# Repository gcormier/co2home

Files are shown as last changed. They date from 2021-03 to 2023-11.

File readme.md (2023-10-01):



# co2home
This device interfaces with an MH-Z19 and makes the data available in home assistant via esphome. It could also work with any other software you'd like on an ESP32. It is powered and programmed via a USB-C port.

Phyiscally, this should also work with the Senseair S8 as it has the same pinouts. ESPHome provides a <a href="https://esphome.io/components/sensor/senseair.html">different block</a> to work with this.

There may be other clones out there as well such as the SYP50-A-5K.

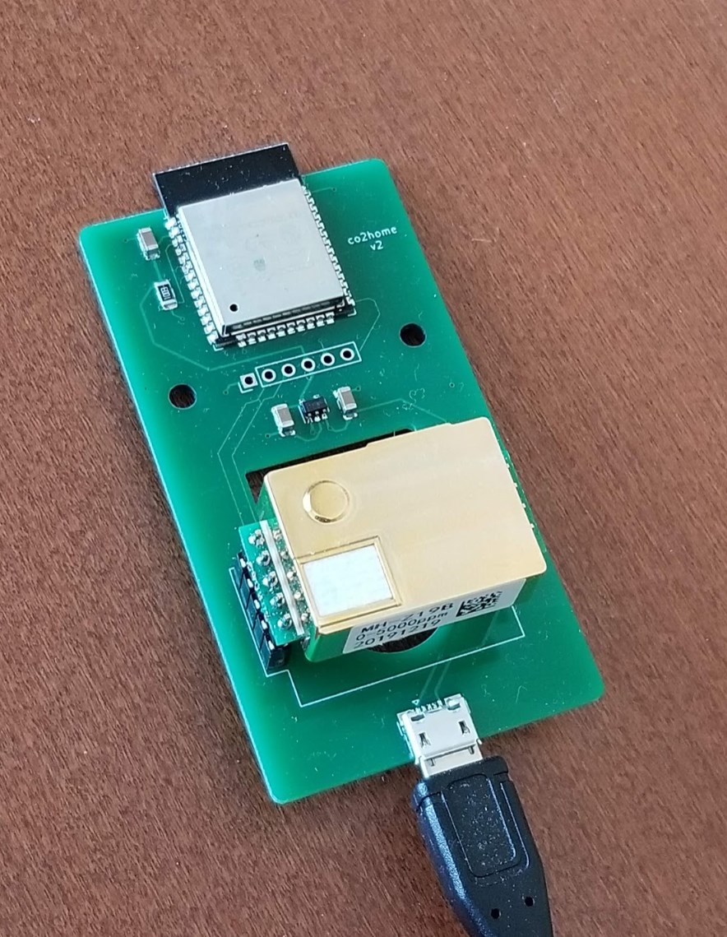
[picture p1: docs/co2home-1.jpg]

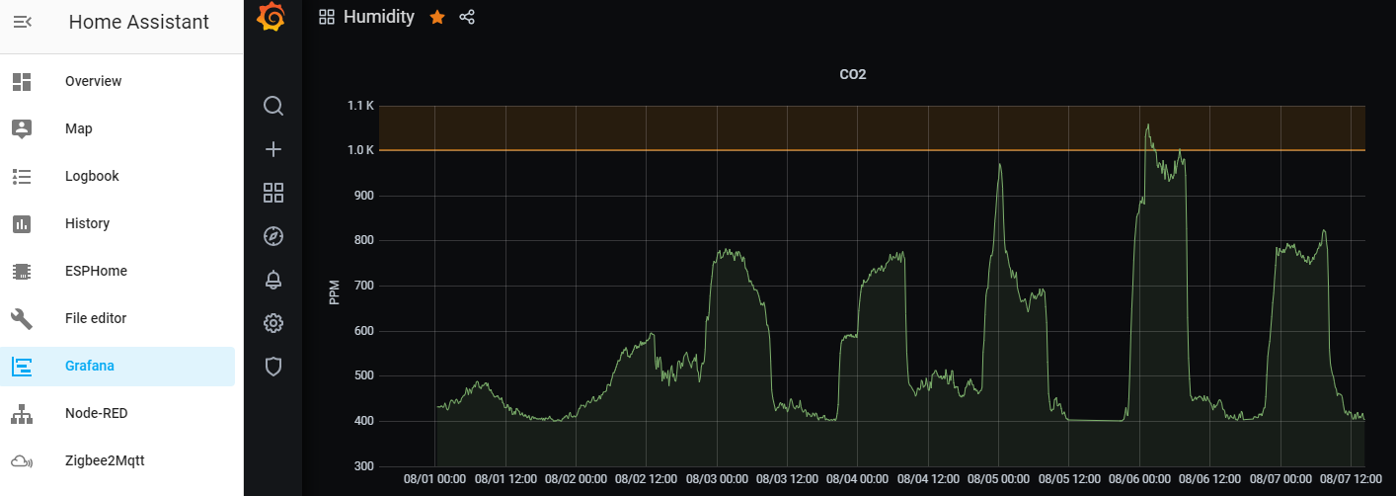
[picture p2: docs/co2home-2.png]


## Narrative
With COVID hitting and basically spending the tail end of Winter and a lot of spring indoors 24x7, I really wanted to check out the indoor air quality. My house does have an ERV, but it was basically a guessing game. No matter how efficient an ERV/HRV is, there is still a penalty to pay. I wanted a way to quantify the levels to adjust my HRV accordingly.

Now with HA and Grafana, I've dialed it in. I have the sensor in my bedroom, but I have just built another board, and I hope to put it somewhere near (or in) a duct to meter the overall CO2 levels in the house. I do want my air handler fan settings to keep the bedroom to acceptable levels at night.

I've found now that 10 minutes an hour is not quite enough ERV time with the CFM I've selected to run it at. Throughout the day, the CO2 level will slowly rise. However, at 20 minutes/hour, it is bringing in enough fresh air to keep levels from rising too much!

Overkill, sure, but hey, why not?

## Programming
The new revision uses an ESP32-C3-MINI-1 which has native USB support. This means the code can be flashed via USB. The first time this is done, you must HOLD the button while plugging in the USB-C cable to force it in programming mode. Flash using `esphome` or any other flasher. Any subsequent flashes do not need any button pushes.

As a backup, there is a programming header - the pinout matches my esp32 programmer, <a href="https://github.com/gcormier/eflashy32/">eflashy32</a> if you are in need of a programmer as well.

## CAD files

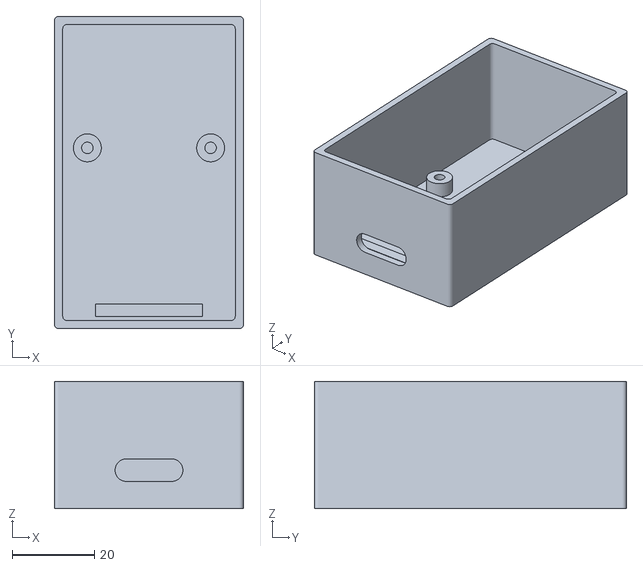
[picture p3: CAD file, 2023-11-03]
3d/co2home base.stl
46.0 x 76.0 x 31.0

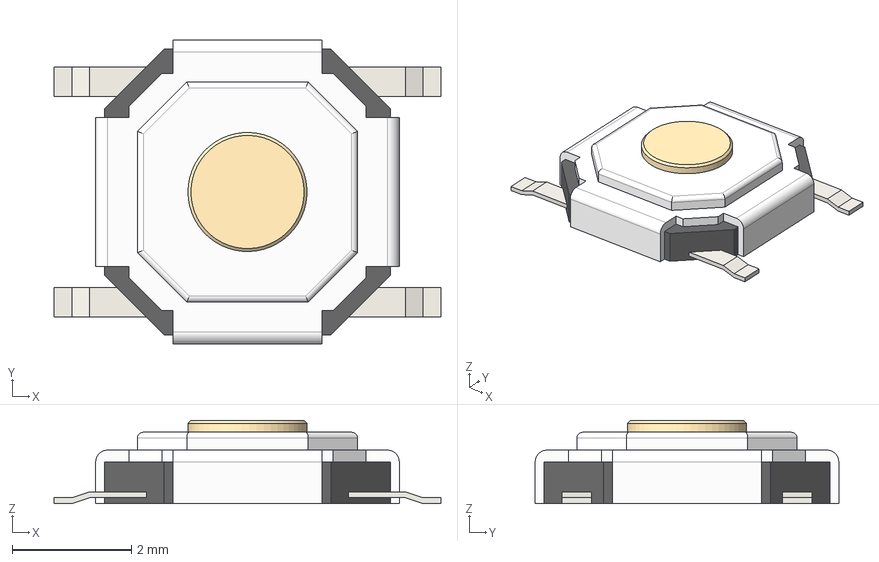
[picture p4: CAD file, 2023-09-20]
pcb/TS-1187A.step
6.50 x 5.10 x 1.40 mm

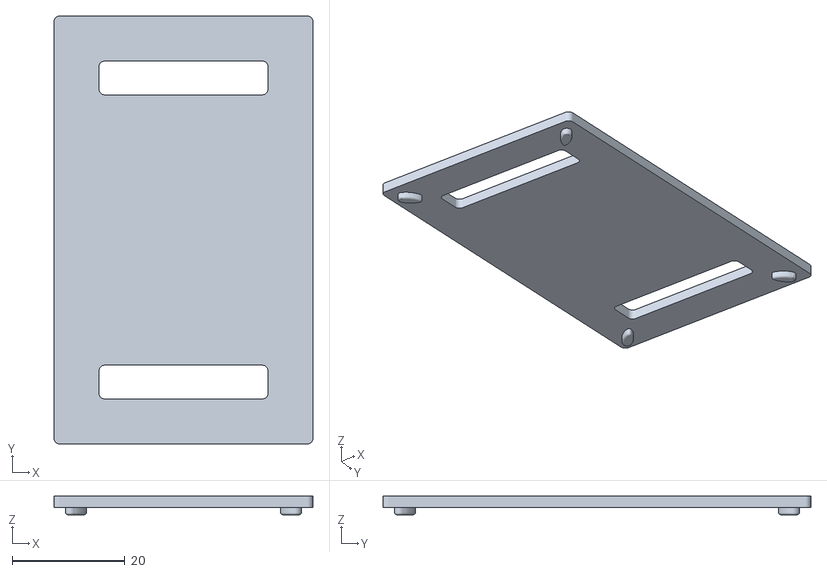
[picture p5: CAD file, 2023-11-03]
3d/co2home lid.stl
46.0 x 76.0 x 3.30

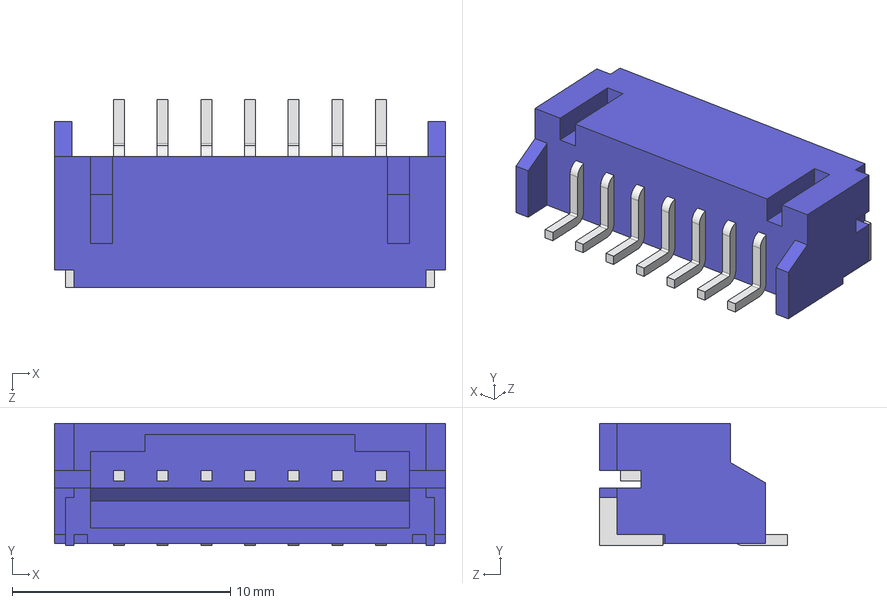
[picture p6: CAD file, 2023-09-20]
pcb/S7B-PH-SM4-TB.STEP
17.9 x 5.60 x 8.60 mm

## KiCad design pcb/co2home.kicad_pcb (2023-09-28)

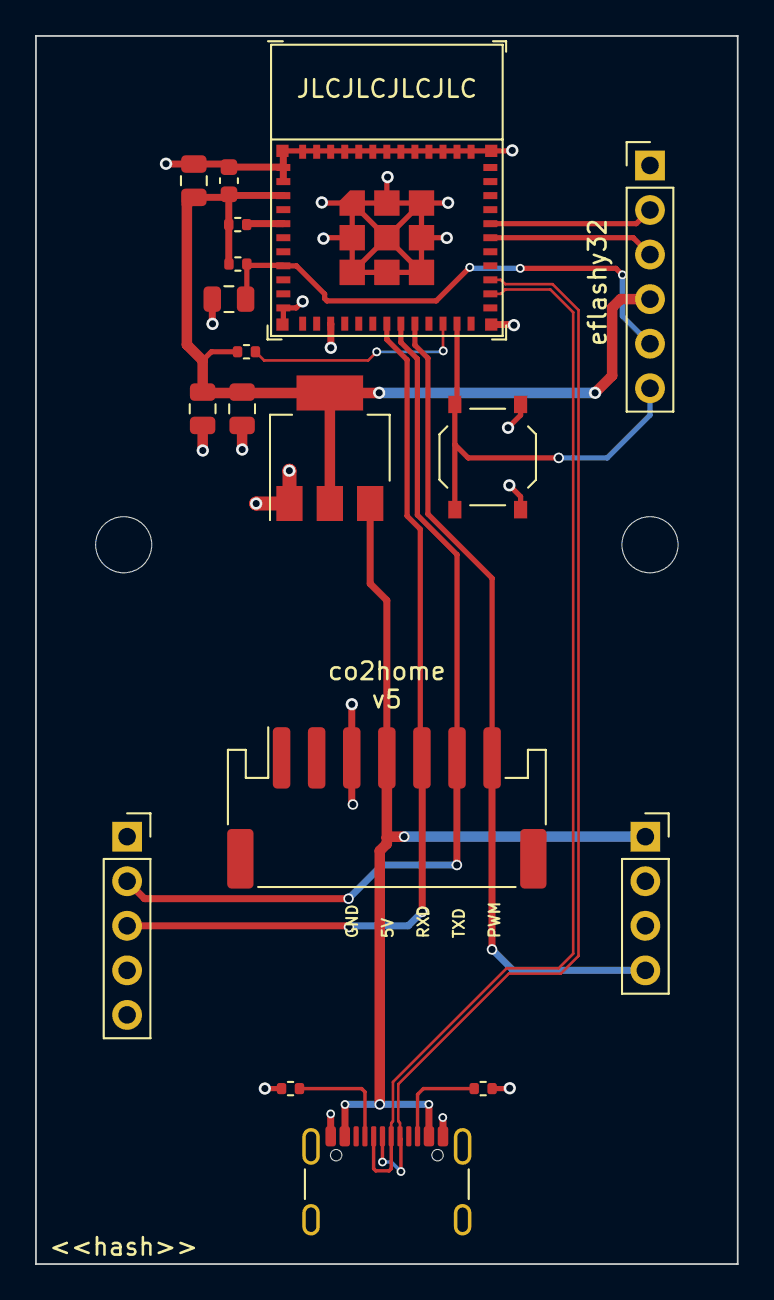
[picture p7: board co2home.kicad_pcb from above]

Board: 2 copper layers, 40.0 x 70.0 mm, 20 parts (0 on the bottom side), 16 nets.

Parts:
C4, C6, C7, C8: 10u; C_0805_2012Metric
C5: 0.1u; C_0603_1608Metric
H1, H2: MountingHole; MountingHole_3.2mm_M3
J1: eflashy32; PinHeader_1x06_P2.54mm_Vertical
J2: MH-Z19 L; PinSocket_1x05_P2.54mm_Vertical
J3: USBC; USB_C_Receptacle_GCT_USB4105-xx-A_16P_TopMnt_Horizontal
J4: MH-Z19 R; PinSocket_1x04_P2.54mm_Vertical
J5: JST-PH; JST_PH_S7B-PH-SM4-TB_1x07-1MP_P2.00mm_Horizontal
R2, R3: 5k1; R_0402_1005Metric
R4, R5, R6: 10k; R_0402_1005Metric
SW1: RESET; SW_Push_1P1T_XKB_TS-1187A
U1: ESP32-C3-MINI-1
U4: AMS1117-3.3; SOT-223-3_TabPin2

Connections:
+3V3: C5.2, C6.2, C7.2, C8.2, J1.4, R4.1, R5.1, R6.1, U1.3 (3V3), U4.2 (VO)
+5V: J3.A4 (VBUS), J3.A9 (VBUS), J3.B4 (VBUS), J3.B9 (VBUS), J4.1, J5.4, U4.3 (VI)
/EN: C4.2, J1.5, R4.2, U1.8 (EN/CHIP_PU)
/GPIO0: J1.6, SW1.1 (A), U1.23 (GPIO9)
/PROGRXD: J1.3, U1.30 (GPIO20/U0RXD)
/PROGTXD: J1.2, U1.31 (GPIO21/U0TXD)
D+: J3.A6 (D+), J3.B6 (D+), U1.27 (GPIO19/USB_D+)
D-: J3.A7 (D-), J3.B7 (D-), U1.26 (GPIO18/USB_D-)
GND: C4.1, C5.1, C6.1, C7.1, C8.1, J1.1, J3.A1 (GND), J3.A12 (GND), J3.B1 (GND), J3.B12 (GND), J4.2, J5.3, R2.2, R3.2, SW1.2 (B), U1.1 (GND), U1.2 (GND), U1.11 (GND), U1.14 (GND), U1.36 (GND), U1.37 (GND), U1.38 (GND), U1.39 (GND), U1.40 (GND), U1.41 (GND), U1.42 (GND), U1.43 (GND), U1.44 (GND), U1.45 (GND), U1.46 (GND), U1.47 (GND), U1.48 (GND), U1.49 (GND), U1.50 (GND), U1.51 (GND), U1.52 (GND), U1.53 (GND), U4.1 (GND)
unnamed: J3.A5 (CC1), R3.1
unnamed: J3.B5 (CC2), R2.1
unnamed: R5.2, U1.5 (GPIO2/ADC1_CH2)
unnamed: R6.2, U1.22 (GPIO8)
PWM: J4.4, J5.7, U1.20 (GPIO6)
RXD: J2.3, J5.5, U1.18 (GPIO4/ADC1_CH4)
TXD: J2.2, J5.6, U1.19 (GPIO5/ADC2_CH0)

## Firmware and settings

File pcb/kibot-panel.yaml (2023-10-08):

kibot:
  version: 1

preflight:
  check_zone_fills: true
  fill_zones: true

filters:
  - name: only_jlc_parts
    comment: 'Only parts with JLC (LCSC) code'
    type: generic
    include_only:
      - column: 'LCSC'
        regex: '^.+'

variants:
  - name: rotated
    comment: 'Just a place holder for the rotation filter'
    type: kibom
    variant: rotated
    pre_transform: _rot_footprint

outputs:
  - name: 'panel'
    type: panelize
    options:
      title: '+ (Panel)'
      units: mm
      configs:
        - layout:
            rows: 1
            cols: 5
            space: 0mm
          tabs:
            type: full
          cuts:
            type: vcuts
            layer: Edge.Cuts
          framing:
            type: railstb
            width: 5mm
            space: 3mm
            fillet: 1mm
          tooling:
            type: 4hole
            hoffset: 5mm
            voffset: 2.5mm
            size: 2mm
          fiducials:
            type: 4fid
            hoffset: 15mm
            voffset: 3.85mm
            coppersize: 1mm
            opening: 2mm
          text:
            type: simple
            text: JLCJLCJLCJLC
            anchor: mt
            voffset: 2.5
            hjustify: center
            vjustify: center
          text2:
            type: simple
            text: Design created on {date} - <<hash>>
            anchor: mb
            voffset: -2.5
            hjustify: center
            vjustify: center
          post:
            refillzones: true

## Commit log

2020-07-09 actually v2?
    [co2buddy-B_Mask.gbr, co2buddy-B_Paste.gbr, co2buddy-B_SilkS.gbr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]
2023-04-02 kicad v7
    [co2home-B_Mask.gbr, co2home-B_Paste.gbr, co2home-B_SilkS.gbr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]
2023-09-20 try to remove 1 model
    [co2home.kicad_pcb]
2023-09-28 remove kicad model
    [co2home.kicad_pcb]
2023-09-28 silkscreen for pins
    [co2home.kicad_pcb]
2023-09-28 PN for headers
    [co2home.kicad_pcb, co2home.kicad_sch]
2023-10-17 esp32c3mini changes
2023-11-03 3d printed case
    [co2home base.stl, co2home lid.stl, co2home-case.step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]
